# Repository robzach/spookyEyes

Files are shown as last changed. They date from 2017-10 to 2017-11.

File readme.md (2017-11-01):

# Spooky Eyes

A (slightly) spooky project for a combined [IDeATe](http://ideate.andrew.cmu.edu) and 
[MechE MakerWing](https://www.cmu.edu/me/news/archive/2015/hamerschlag-makerwing.html)  Halloween 
at Carnegie Mellon University.

When the photosensor sees less light, the lights blink faster, and vice versa. Turn the potentiometer to adjust the blinking rate. It's *super scary*. We can give hugs as needed.

# Let's make it!

## Parts list

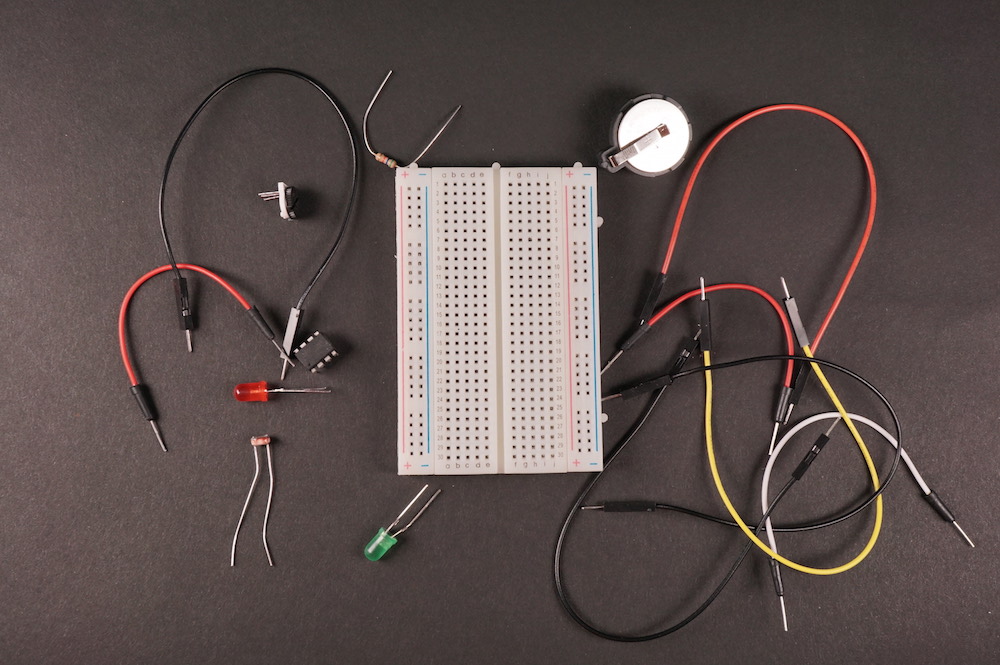
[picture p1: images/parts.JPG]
parts


* 1 ATTiny85 microcontroller
* 1 5.6kΩ resistor
* 1 photoresistor
* 1 10kΩ potentiometer
* 2 LEDs
* 1 medium solderless breadboard
* ~8 male–male jumper wires
* 6 female–male jumper wires (optional—for extending light sensor and LEDs off the breadboard)
* 1 2032 3V lithium coin cell battery
* 1 coin cell battery holder
* spooky thing to put your LEDs and light sensor onto

## If you are comfortable with electronics and reading a schematic

The Arduino sketch has been preloaded onto the ATTiny85 chip. Just build the circuit as [the 
schematic](spookyEyes_schem.png) indicates, and the LEDs should begin blinking as soon as the chip is powered.

Want to customize the behavior? Great! We have a USB programmer so we can flash new firmware onto 
the ATTiny super easily. Just modify the Arduino sketch and share the code with us, so we can 
upload it for you. (There's a bit of setup to get the programmer to work on each machine, but if 
you want to do the setup on your own machine that's fine too.)

## If you are newer to electronicsland

### 1. Welcome! We're glad you're here.

### 2. Let's start with the ATTiny85 chip, which will drive the whole project. 

The one we're 
supplying has been pre-programmed with instructions to read the ambient light level and combine 
that with information from the potentiometer to establish the rate at which the LEDs will blink.

Put the chip onto the breadboard like so:
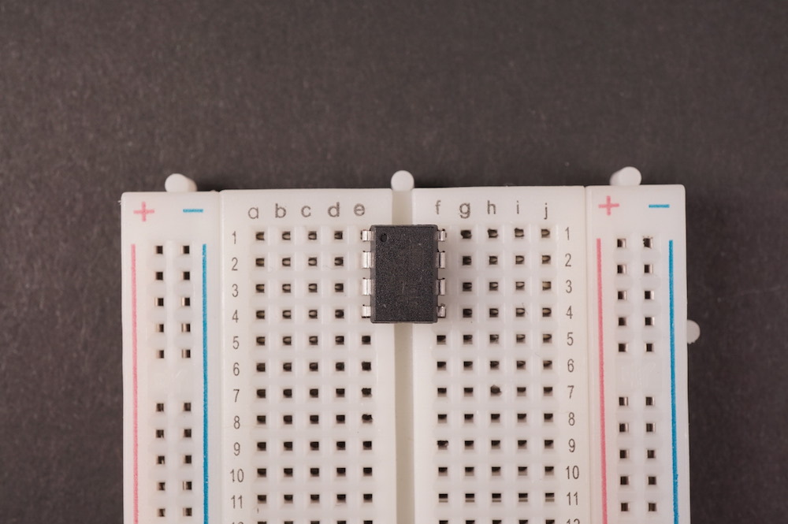
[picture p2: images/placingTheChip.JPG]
placing the chip


**Pay attention to the dot on the chip and make sure it's in the upper left corner!** (In the 
schematic
drawing a half-circle is shown. This and the little dot are interchangeable and serve to mark the top of the chip.)

This tutorial refers to the *software* numbers each of the chip's 
hardware pins use. For instance, if you make an attachment to software `pin 0`, that means the 
chip's lower right pin, which has hardware number 5. Below is a schematic of the chip showing the 
hardware and software numbers; the hardware numbers are the 1–8 sequence written on the chip, and the software numbers appear in cyan and red circles.

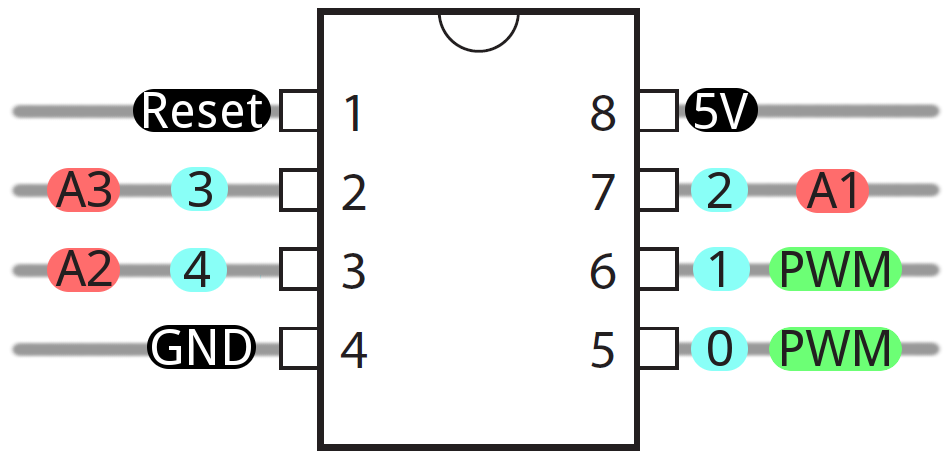
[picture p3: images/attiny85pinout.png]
ATTiny85 pinout with hardware and software pin designations

Image from Sparkfun, shared under the [CC BY-SA 4.0 
license](https://creativecommons.org/licenses/by-sa/4.0/)

Let's give the chip power: use a jumper wire to connect the chip's `5V` pin to the column marked 
with a + and a red line along the edge of the breadboard. Use another jumper to connect the 
chip's `GND` (ground) to the column marked with – and a blue line along the breadboard edge.

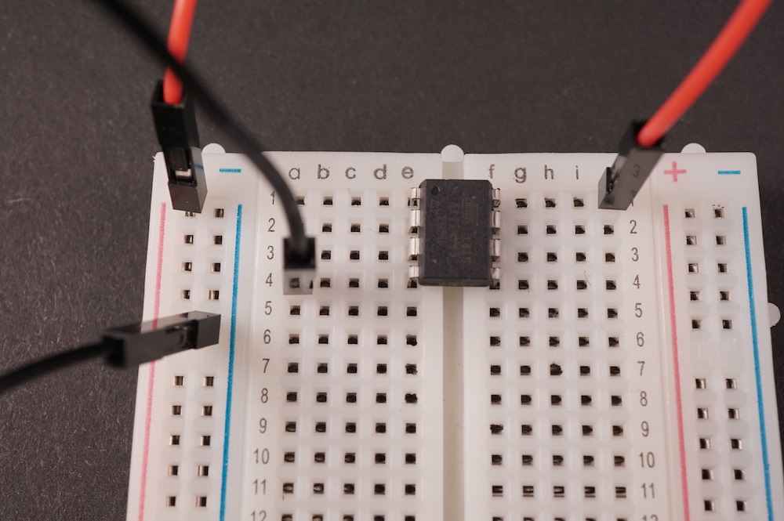
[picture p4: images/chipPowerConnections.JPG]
chip power connections


### 3. Now we can add some LEDs. 

LEDs have a longer and a shorter leg, and they only work 
when power flows through them in the correct direction. The longer leg is the positive one, and 
the shorter is the negative.

Get an LED and plug the long leg into the same row as `pin 0`, and the short leg into another row 
on the breadboard that is not shared with any of the ATTiny pins. For the second LED, plug its 
long leg into `pin 1` and the short leg into that same row as the other's short leg.

Use a jumper wire to connect the short leg row to the ground column (with the – at the top and a 
blue stripe).

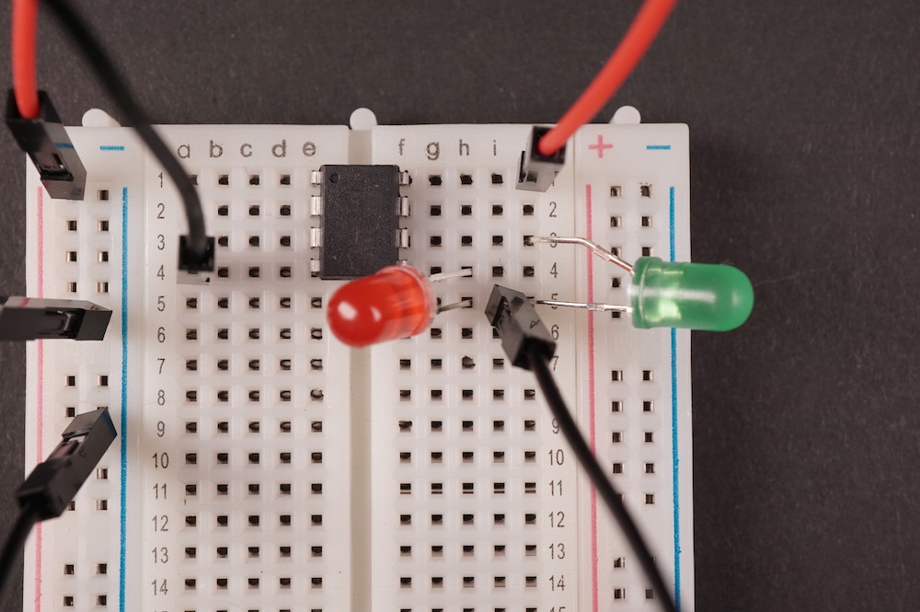
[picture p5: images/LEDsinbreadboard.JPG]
LEDs in breadboard


### 4. Add the potentiometer

The potentiometer has three legs: two outsides and one in the center. Plug the potentiometer into 
the breadboard so each leg is in a different row (i.e. the legs are oriented up-down along a 
column, not left-right along a row).

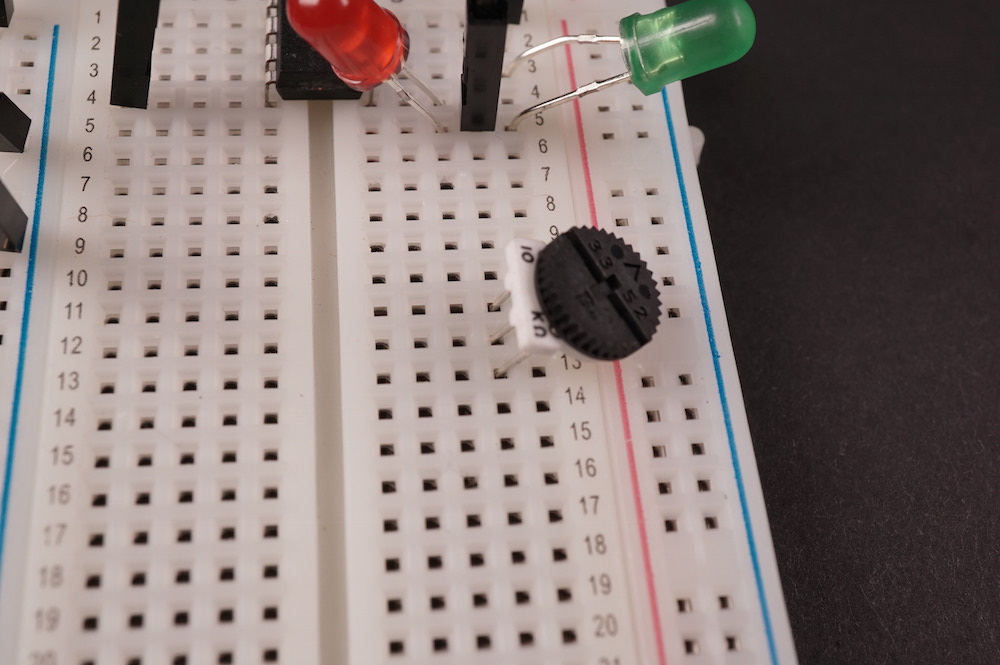
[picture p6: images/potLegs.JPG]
pot legs


Use a jumper wire to connect one of the outside legs to the long column marked with a minus sign, 
and use a second jumper wire to connect the potentiometer's other outside leg to the long column 
marked with a plus sign.

Use a third jumper wire to connect the potentiometer's center pin to ATTiny `pin A3`.

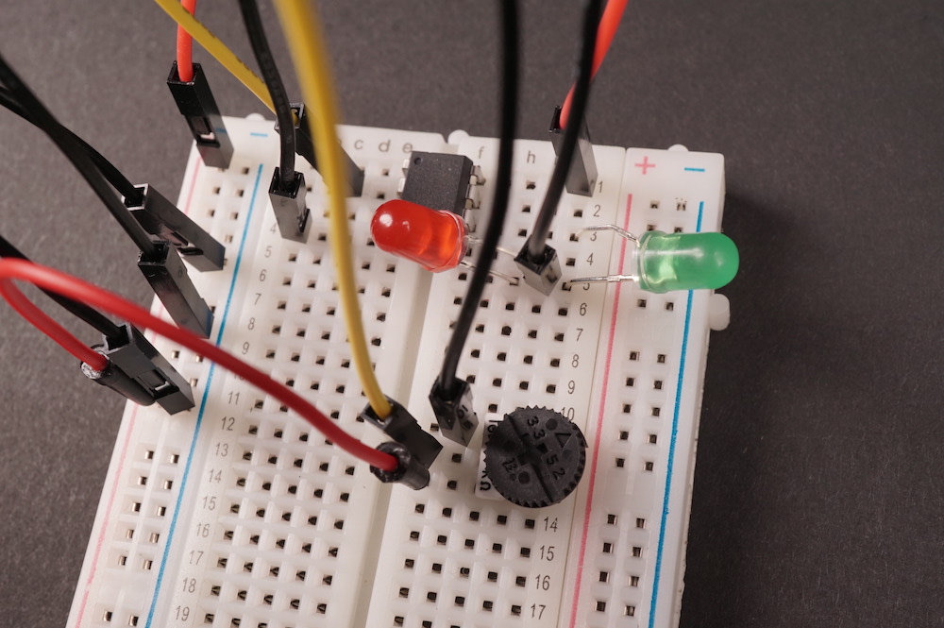
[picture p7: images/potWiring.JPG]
pot wiring


### 5. Add the light sensor

Wire the 5.6kΩ resistor so one leg goes into the long column marked with the minus sign, and the 
other leg goes into any unused row.

Then, wire the photoresistor so that one leg goes into the long column marked with the plus sign, 
and 
the other leg is in the same row the resistor plugs into.

Use a jumper wire to connect that shared row to ATTiny `pin A2`.

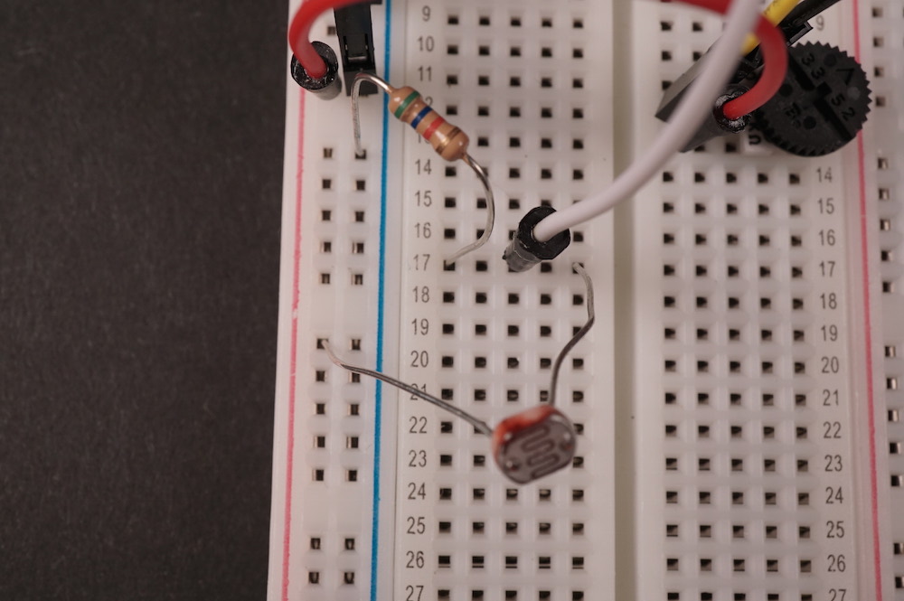
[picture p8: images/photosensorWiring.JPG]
photosensor wiring


### 6. Add power and you're done!

Slide the battery into the battery case, with the positive side (marked with a +) facing up.

This next part is tricky: place the battery case on the breadboard so its negative leg is in the 
negative (– sign and blue stripe) column, and its positive leg is somewhere else on the board.

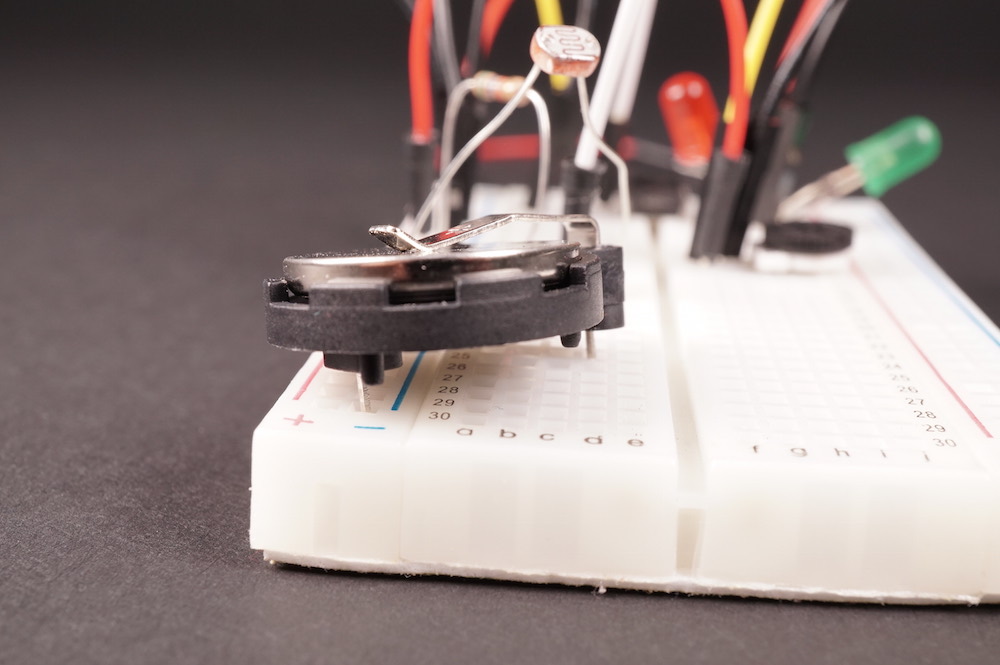
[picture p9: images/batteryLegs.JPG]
battery


Then use a jumper to attach the battery's positive leg to the power (red stripe and + sign) 
column.

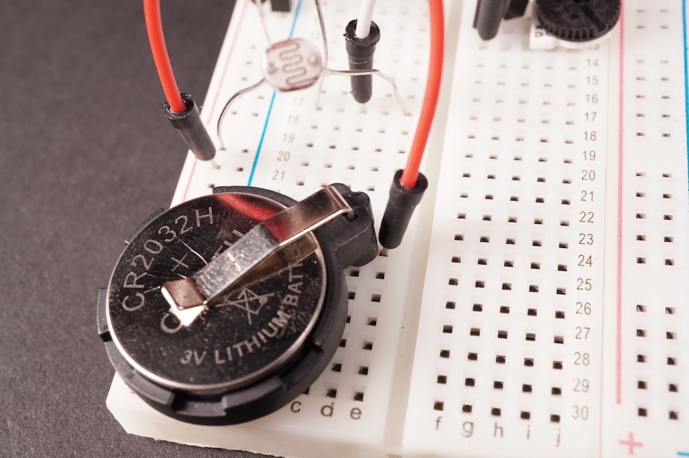
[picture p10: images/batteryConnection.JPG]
battery connection


The lights should start blinking, and if they don't it's time to debug!

## Extending the LEDs and light sensor

If you want the LEDs or light sensor to be somewhere other than the main board, simply use the 
female–male jumper wires like extension cords. Easy!

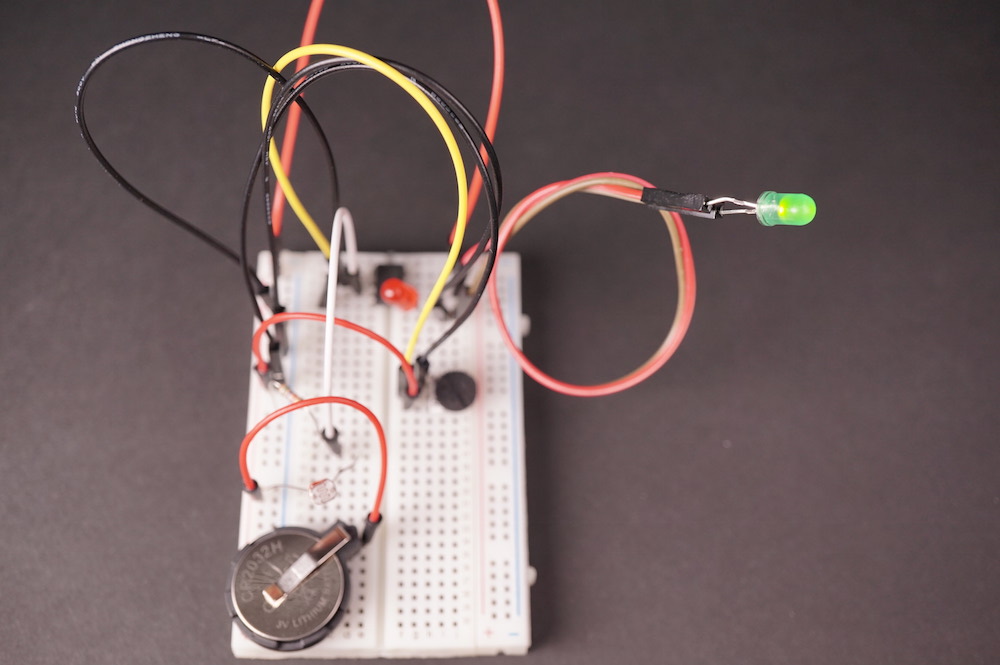
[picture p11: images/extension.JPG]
extension


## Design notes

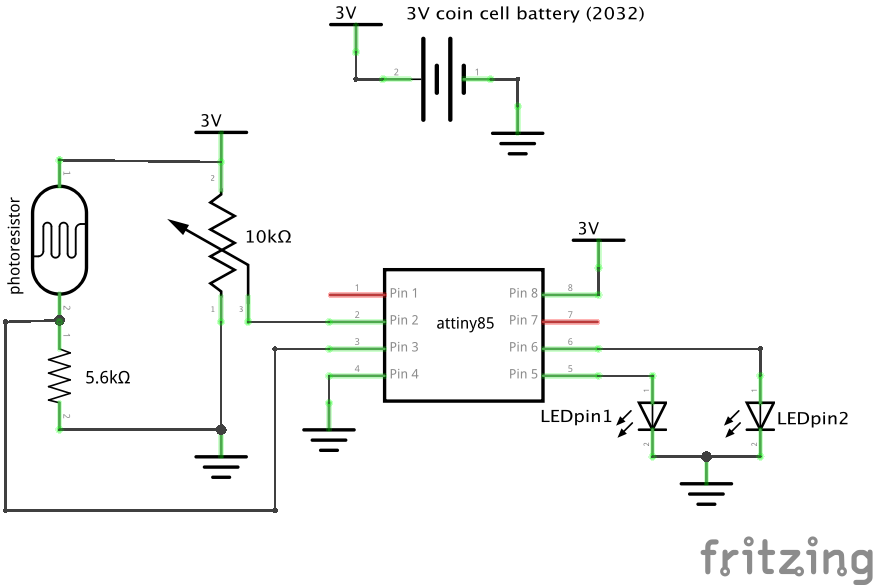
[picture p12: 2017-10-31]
spookyEyes_schem.png

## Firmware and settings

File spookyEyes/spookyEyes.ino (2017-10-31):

/*
   Spooky eyes blink at different rates based on ambient light levels
   (useful for frightening squirrels and other gentle passers by)

   Light level detection is auto-ranging and blink rate is tweaked by a potentiometer 
   on pin A3. An ATTiny85 does the computing, powered by a 3V lithium battery (2032). 
   A photocell in a 5.6kΩ voltage divider circuit provides analog light level input 
   to pin A2. Two LEDs are driven by pins 0 and 1 of the ATTiny.
   
   See e.g. http://highlowtech.org/wp-content/uploads/2011/10/ATtiny45-85.png for the 
   chip pinout to be sure you're matching software numbers to hardware numbers properly.

   10/31/17
   released to the public domain by the author
   Robert Zacharias, rzach@cmu.edu
*/

                              // pin assignments on ATTiny85
const int LEDpin1 = 0;        // LED on hardware pin 5 (lower right corner)
const int LEDpin2 = 1;        // another LED on hardware pin 6 (one above lower right corner)
const int potPin = A3;        // 10k potentiometer wiper on hardware pin 2 (one below upper left corner)
const int photosensePin = A2; // voltage divider from photocell to hardware pin 3 (one above lower left corner)

long last = 0; // will be used for blink timing

// start the eye LEDs in opposite states (change both to same value to blink in synchrony)
bool LEDstate1 = false;
bool LEDstate2 = true;

// variables to store highest and lowest values seen
int highestSeen, lowestSeen;

void setup() {
  pinMode(LEDpin1, OUTPUT);
  pinMode(LEDpin2, OUTPUT);
  pinMode(potPin, INPUT);
  pinMode(photosensePin, INPUT);
}

void loop() {
  int photoVal = analogRead(photosensePin);

  // set highest and lowest values based on ongoing observation; these start fresh on chip restart
  if (photoVal > highestSeen) highestSeen = photoVal;
  if (photoVal < lowestSeen) lowestSeen = photoVal;
  
  int photoScale = map(photoVal, lowestSeen, highestSeen, 10, 200);

  int potVal = analogRead(potPin);
  float multiplier = mapfloat(potVal, 0, 1023, 0.25, 4);

  int wait = photoScale * multiplier; // use pot to adjust blink rate

  // flip LED states if it has been long enough
  if (millis() - last > wait) {
    LEDstate1 = !LEDstate1;
    LEDstate2 = !LEDstate2;
    last = millis();
  }

  digitalWrite(LEDpin1, LEDstate1);
  digitalWrite(LEDpin2, LEDstate2);
}


// Arduino's built in map() function does integer math only, so it's necessary to define with floats to get float results
float mapfloat(float x, float in_min, float in_max, float out_min, float out_max)
{
  return (x - in_min) * (out_max - out_min) / (in_max - in_min) + out_min;
}

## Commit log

2017-10-31 initial upload
    [spookyEyes.fzz]
2017-10-31 added schematic
    [spookyEyes.fzz]
2017-10-31 added link to schematic
